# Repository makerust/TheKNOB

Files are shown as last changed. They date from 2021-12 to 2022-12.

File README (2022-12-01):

# TheKNOB

# First Time Setup for development
`git pull --recurse-submodules`
Sketch > Include Library > Add .ZIP Library
Navigate to the ESP library in thirdparty

In:
File > Preference > Additional Boards Manager URLS
Add:
`https://dl.espressif.com/dl/package_esp32_index.json, http://arduino.esp8266.com/stable/package_esp8266com_index.json`
Select:
Tools > Board > Board Manager
Search: ESP32
Install Board Library
Select:
Tools > Board > Board Manager > ESP32 Dev Module

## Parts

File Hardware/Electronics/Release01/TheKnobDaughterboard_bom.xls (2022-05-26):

Comment | Designator | Footprint | JLCPCB Part #
1k | R2 | Resistor_SMD:R_0603_1608Metric | C21190
1.5k | R6 | Resistor_SMD:R_0603_1608Metric | C22843
100k | R17,R19 | Resistor_SMD:R_0603_1608Metric | C25803
100nF | C1 | Capacitor_SMD:C_0603_1608Metric | C14663
10k | R9,R10,R11,R12,R15,R20 | Resistor_SMD:R_0603_1608Metric | C25804
10uF | C4 | Capacitor_SMD:C_0603_1608Metric | C19702
16k | R14 | Resistor_SMD:R_0603_1608Metric | C269411
3.6v | D1,D2 | Diode_SMD:D_SOD-323_HandSoldering | C391443
330R | R5 | Resistor_SMD:R_0603_1608Metric | C23138
33pF | C7,C10,C11 | Capacitor_SMD:C_0603_1608Metric | C1663
47uF | C2,C8,C9 | Capacitor_SMD:C_1206_3216Metric | C68361
3k | R1 | Resistor_SMD:R_0603_1608Metric | C4211
470k | R16,R18 | Resistor_SMD:R_0603_1608Metric | C23178
5.1k | R3,R4 | Resistor_SMD:R_0603_1608Metric | C23186
500mA | F1 | Fuse:Fuse_1206_3216Metric | C70076
6.8uH | L1,L2 | Inductor_SMD:L_1210_3225Metric | C223416
75R | R7,R8 | Resistor_SMD:R_0603_1608Metric | C4275
80k | R13 | Resistor_SMD:R_0603_1608Metric | C23249
AP9101CK | U2 | Package_TO_SOT_SMD:SOT-23-5 | C507889
D_Schottky | D3,D4,D5 | Diode_SMD:D_SOD-123 | C37049
JST PH 2 Pin Surface Mount | J1 | JST_PH_S2B-PH-SM4-TB | C295747
LMR62421XMF/NOPB | U3 | Package_SO:VSSOP-8_3.0x3.0mm_P0.65mm | C206031
MCP73831-5-OT | U1 | Package_TO_SOT_SMD:SOT-23-5 | C424093
Q_NMOS_GSD | Q1,Q2 | Package_TO_SOT_SMD:SOT-23 | C20917
USB_C_Receptacle_USB2.0 | J2 | Connector_USB:USB_C_Receptacle_HRO_TYPE-C-31-M-12 | C165948

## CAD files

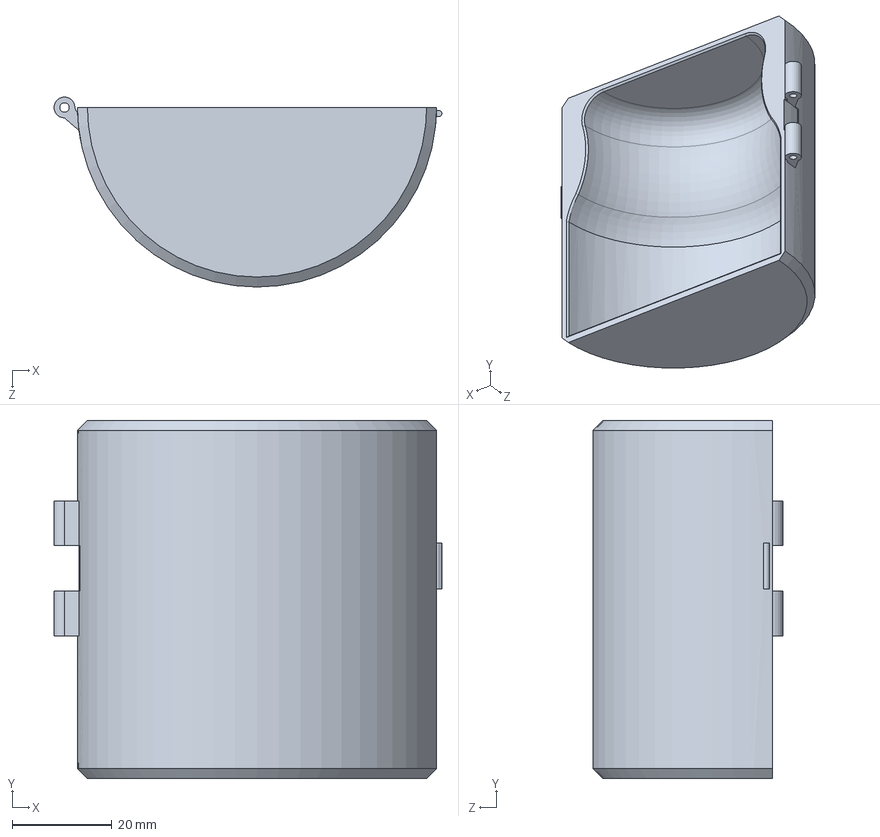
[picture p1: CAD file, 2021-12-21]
Hardware/CaseAndMechanism/SolidworksFiles/Case2_2^KNOBAssembly.SLDPRT
77.7 x 71.7 x 38.1 mm

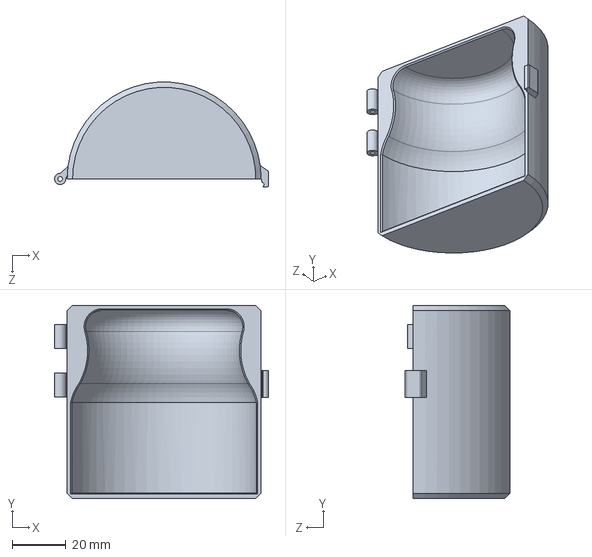
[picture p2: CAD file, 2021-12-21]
Hardware/CaseAndMechanism/SolidworksFiles/Case1^KNOBAssembly.SLDPRT
79.3 x 71.7 x 38.8 mm

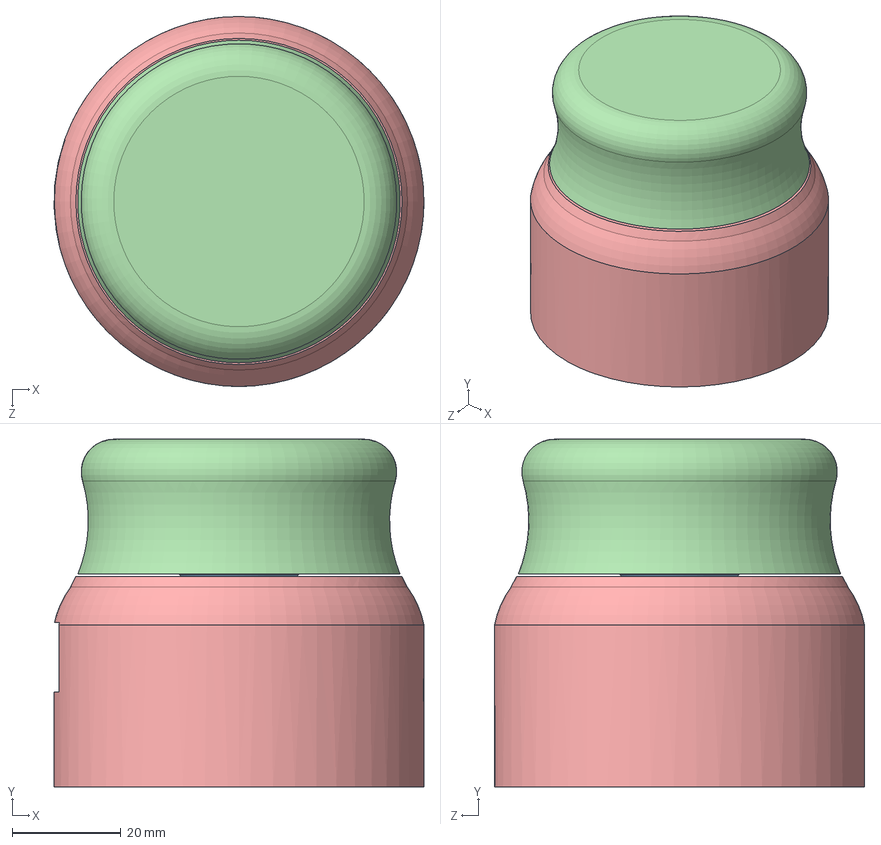
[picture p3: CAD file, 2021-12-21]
Hardware/CaseAndMechanism/SolidworksFiles/KNOBAssembly.SLDASM
68.0 x 63.9 x 68.0 mm
EncoderDevBoard^KNOBAssembly
ESP32DevBoard^KNOBAssembly
5972K91_Ball Bearing
KNOB^KNOBAssembly
KNOBBase^KNOBAssembly
9714K2_Wave Disc Spring
93475A280_18-8 Stainless Steel Washer
LiPoChargeDevBoard
BatteryPrism650mAh
AlpsSKPMAME010 x 2
Bottom_TheKnob
Switch_1587768^KNOBAssembly
NeoPixelPCBA x 3

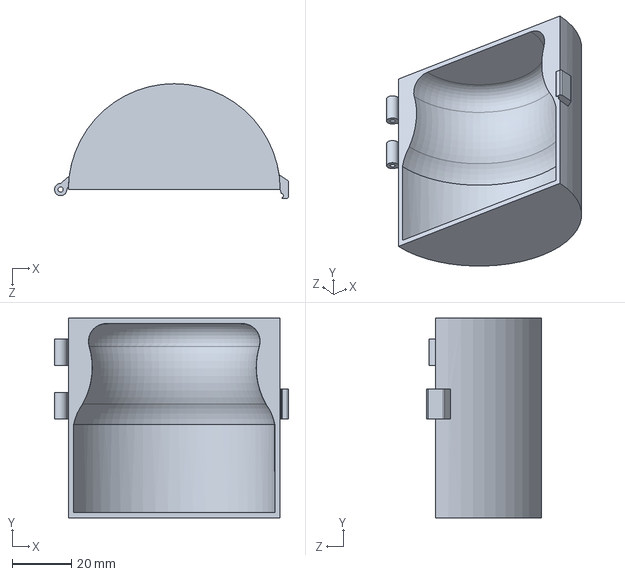
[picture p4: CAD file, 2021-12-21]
Hardware/CaseAndMechanism/SolidworksFiles/Case2^KNOBAssembly.SLDPRT
79.2 x 67.6 x 38.8 mm

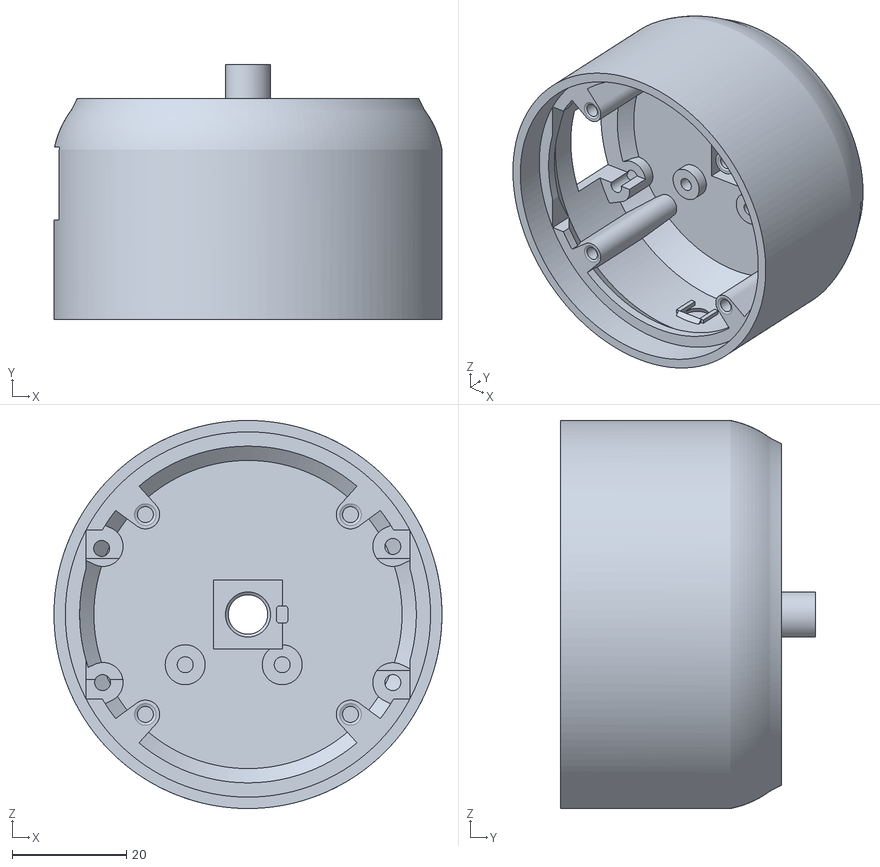
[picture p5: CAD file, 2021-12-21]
Hardware/CaseAndMechanism/STLFiles/Base.STL
68.0 x 44.7 x 68.0

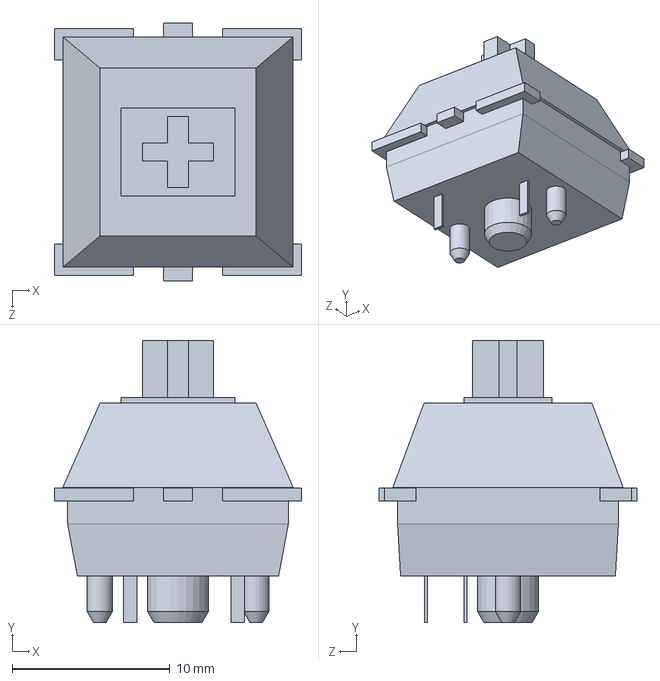
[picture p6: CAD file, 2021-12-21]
Hardware/CaseAndMechanism/SolidworksFiles/cherry mx.SLDPRT
15.6 x 17.9 x 16.3 mm

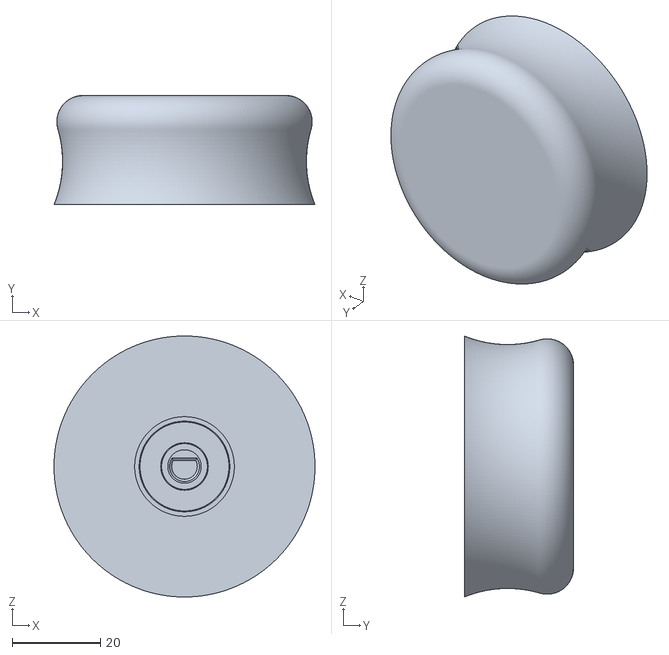
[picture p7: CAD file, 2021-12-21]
Hardware/CaseAndMechanism/STLFiles/Knob.STL
59.3 x 24.8 x 59.3

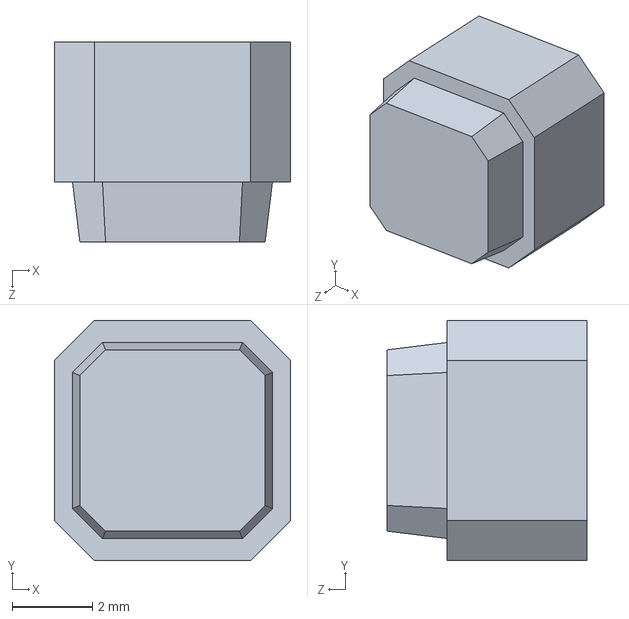
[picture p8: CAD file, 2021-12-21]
Hardware/CaseAndMechanism/SolidworksFiles/AlpsSKPMAME010.SLDPRT
5.90 x 6.00 x 5.00 mm

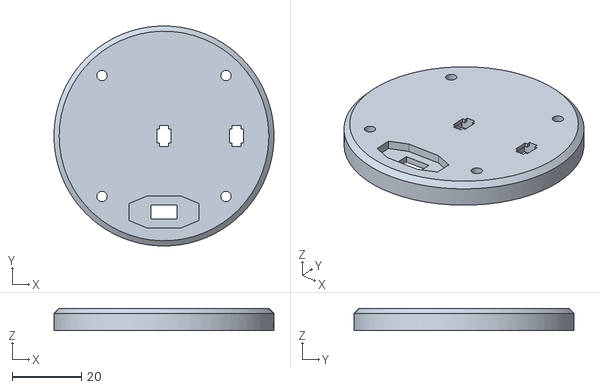
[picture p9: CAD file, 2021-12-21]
Hardware/CaseAndMechanism/STLFiles/Case.STL
63.7 x 63.7 x 6.50

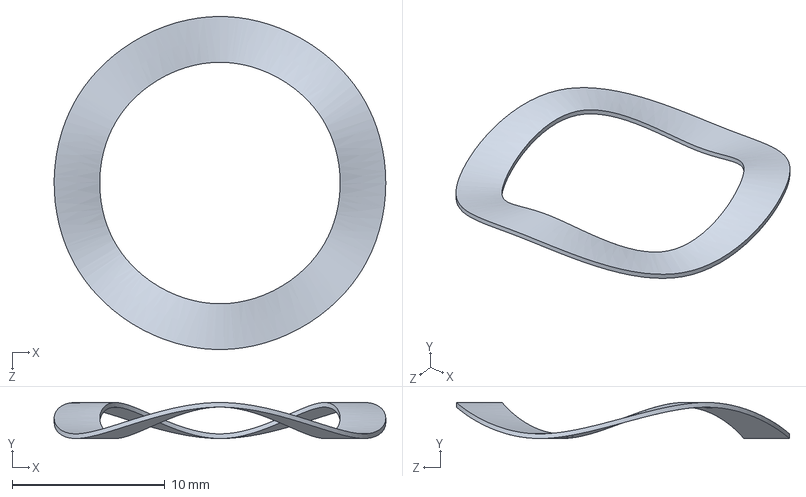
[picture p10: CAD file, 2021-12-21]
Hardware/CaseAndMechanism/SolidworksFiles/9714K2_Wave Disc Spring.SLDPRT
21.7 x 2.36 x 21.8 mm

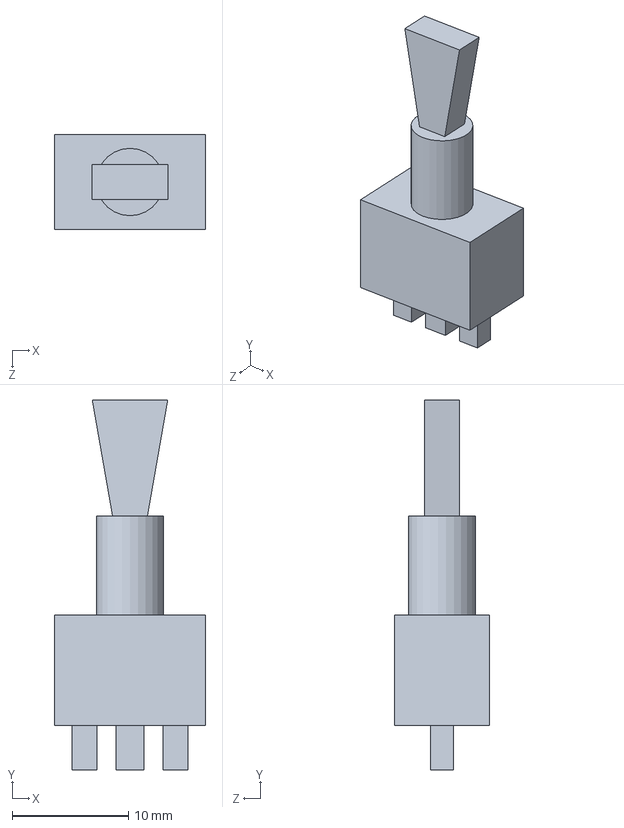
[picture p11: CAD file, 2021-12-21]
Hardware/CaseAndMechanism/SolidworksFiles/ToggleSwitch.SLDPRT
13.0 x 31.9 x 8.15 mm

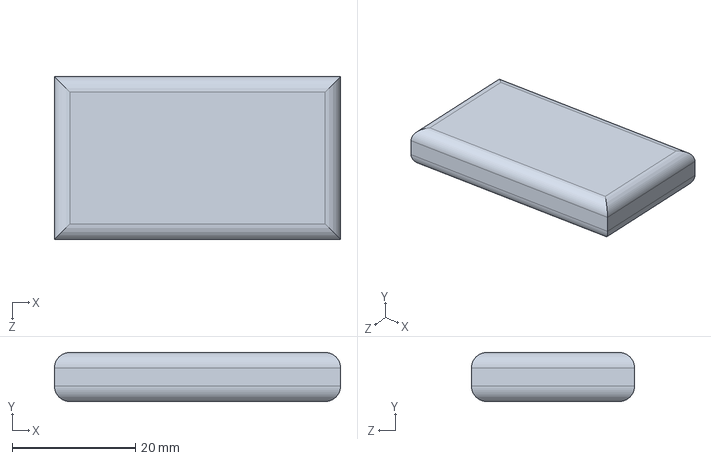
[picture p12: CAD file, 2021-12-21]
Hardware/CaseAndMechanism/SolidworksFiles/BatteryPrism650mAh.SLDPRT
46.5 x 8.00 x 26.5 mm

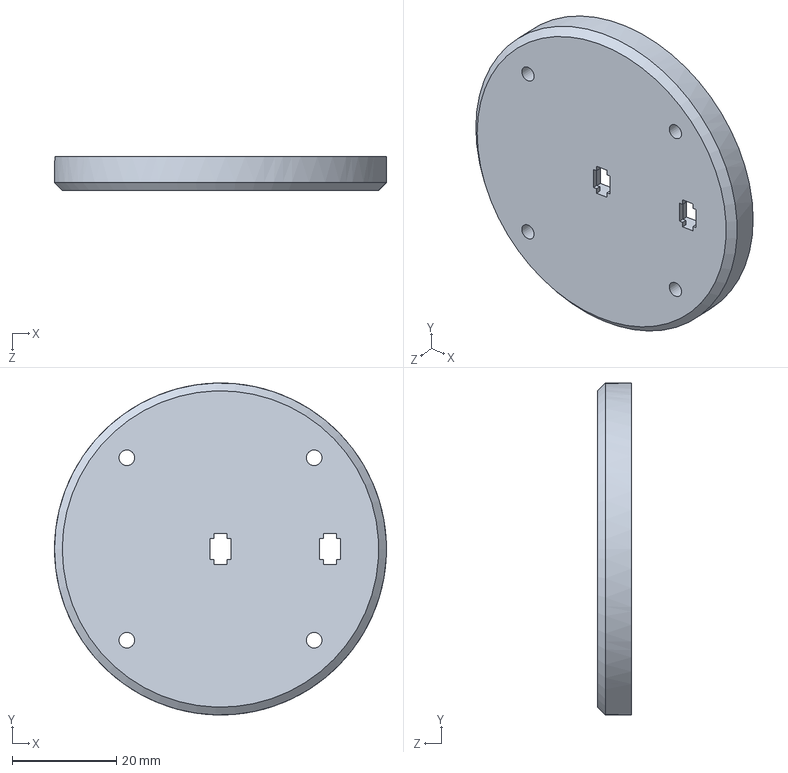
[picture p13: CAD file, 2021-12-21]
Hardware/CaseAndMechanism/SolidworksFiles/BottomButtonTestPrint1.SLDPRT
63.7 x 63.7 x 6.50 mm

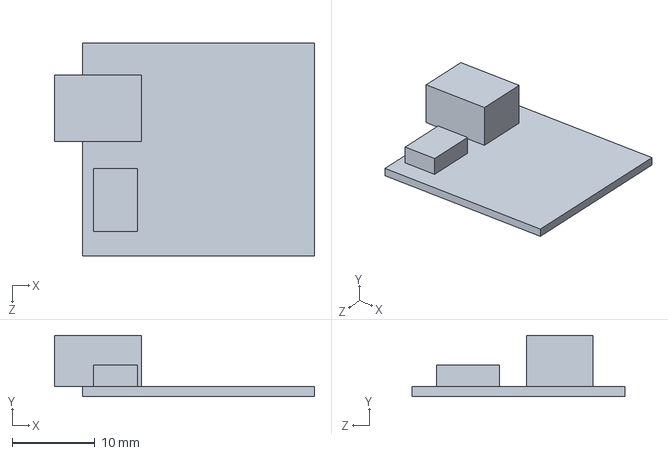
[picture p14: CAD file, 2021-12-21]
Hardware/CaseAndMechanism/SolidworksFiles/LiPoChargeDevBoard.SLDPRT
31.4 x 7.40 x 25.8 mm

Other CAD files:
Hardware/CaseAndMechanism/SolidworksFiles/Bottom_TheKnob.SLDPRT
Hardware/CaseAndMechanism/SolidworksFiles/NeoPixelPCBA.SLDPRT
Hardware/CaseAndMechanism/SolidworksFiles/9714K428_Wave Disc Spring.SLDPRT
Hardware/CaseAndMechanism/SolidworksFiles/98689A118_General Purpose 18-8 Stainless Steel Washer.SLDPRT
Hardware/CaseAndMechanism/SolidworksFiles/5972K91_Ball Bearing.SLDPRT
Hardware/CaseAndMechanism/SolidworksFiles/93475A280_18-8 Stainless Steel Washer.SLDPRT

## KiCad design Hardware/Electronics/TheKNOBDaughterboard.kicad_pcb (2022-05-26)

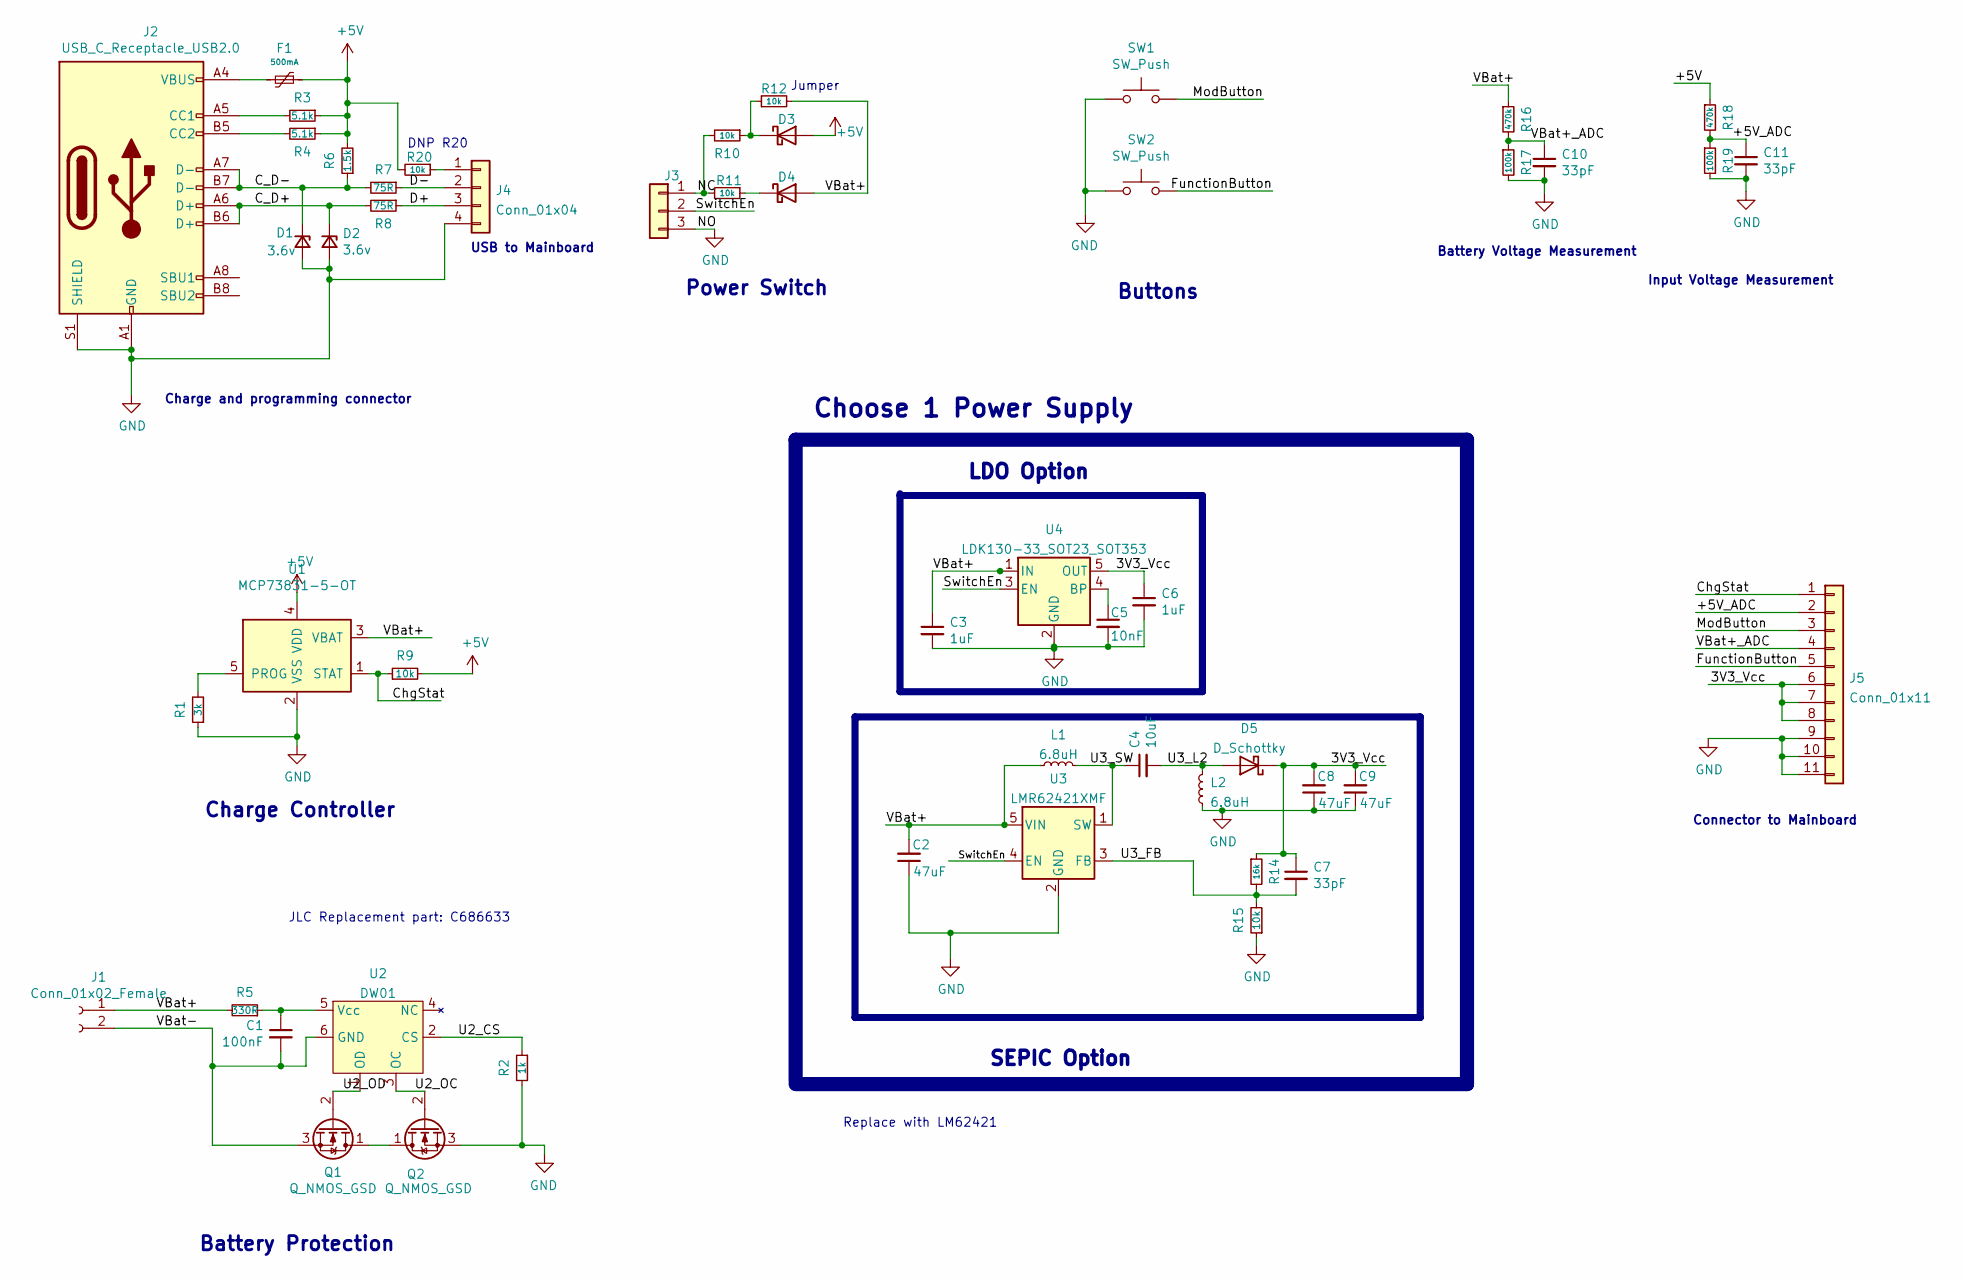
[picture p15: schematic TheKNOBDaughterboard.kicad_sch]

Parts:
C1: 100nF; C_0603_1608Metric
C2, C8, C9: 47uF; C_1206_3216Metric; MFR_PN C3216X5R1A336MTJ00N
C3, C6: 1uF; C_0603_1608Metric
C4: 10uF; C_0603_1608Metric
C5: 10nF; C_0603_1608Metric
C7, C10, C11: 33pF; C_0603_1608Metric
D1, D2: 3.6v; D_SOD-323_HandSoldering; MFR_PN BZT52-B3V6S_R1_00001
D3, D4, D5: D_Schottky; D_SOD-123; MFR_PN 1N5819HW
F1: 500mA; Fuse_1206_3216Metric; MFR_PN nSMD025
J1: Conn_01x02_Female; JST_PH_S2B-PH-SM4-TB_1x02-1MP_P2.00mm_Horizontal
J2: USB_C_Receptacle_USB2.0; USB_C_Receptacle_HRO_TYPE-C-31-M-12; MFR_PN TYPE-C-31-M-12
J3: Conn_01x03; JST_EH_B3B-EH-A_1x03_P2.50mm_Vertical
J4: Conn_01x04; JST_EH_B4B-EH-A_1x04_P2.50mm_Vertical
J5: Conn_01x11; JST_EH_B11B-EH-A_1x11_P2.50mm_Vertical
L1, L2: 6.8uH; L_1210_3225Metric; MFR_PN LBC3225T6R8MR
Q1, Q2: Q_NMOS_GSD; SOT-23; MFR_PN AO3400A
R1: 3k; R_0603_1608Metric
R2: 1k; R_0603_1608Metric
R3, R4: 5.1k; R_0603_1608Metric
R5: 330R; R_0603_1608Metric
R6: 1.5k; R_0603_1608Metric
R7, R8: 75R; R_0603_1608Metric
R9, R10, R11, R12, R15, R20: 10k; R_0603_1608Metric
R14: 16k; R_0603_1608Metric
R16, R18: 470k; R_0603_1608Metric
R17, R19: 100k; R_0603_1608Metric
SW1, SW2: SW_Push; ALPS_SKPM
U1: MCP73831-5-OT; SOT-23-5
U2: DW01; SOT-23-6
U3: LMR62421XMF; SOT-23-5
U4: LDK130-33_SOT23_SOT353; SOT-353_SC-70-5

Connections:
+5V: D3.2 (A), F1.1, R3.1, R4.1, R6.2, R9.2, R18.1, R20.2, U1.4 (VDD)
/3V3_Vcc: C6.1, C7.1, C8.2, C9.2, D5.1 (K), J5.6, J5.7, J5.8, R14.1, U4.5 (OUT)
/+5V_ADC: C11.1, J5.2, R18.2, R19.1
/C_D+: D2.1 (K), J2.A6 (D+), J2.B6 (D+), R8.2
/C_D-: D1.1 (K), J2.A7 (D-), J2.B7 (D-), R6.1, R7.2
/ChgStat: J5.1, R9.1, U1.1 (STAT)
/D+: J4.3, R8.1
/D-: J4.2, R7.1
/FunctionButton: J5.5, SW2.1
/ModButton: J5.3, SW1.1
/NC: J3.1, R10.2, R11.2
/SwitchEn: J3.2, U3.4 (EN), U4.3 (EN)
/U2_CS: R2.1, U2.2 (CS)
/U2_OC: Q2.2 (G), U2.3 (OC)
/U2_OD: Q1.2 (G), U2.1 (OD)
/U3_FB: C7.2, R14.2, R15.2, U3.3 (FB)
/U3_L2: C4.2, D5.2 (A), L2.2
/U3_SW: C4.1, L1.2, U3.1 (SW)
/VBat+: C2.2, C3.1, D4.2 (A), J1.1, J1.MP, L1.1, R5.2, R12.2, R16.1, U1.3 (VBAT), U3.5 (VIN), U4.1 (IN)
/VBat+_ADC: C10.1, J5.4, R16.2, R17.1
/VBat-: C1.2, J1.2, Q1.3 (S), U2.6 (GND)
GND: C2.1, C3.2, C5.2, C6.2, C8.1, C9.1, C10.2, C11.2, D1.2 (A), D2.2 (A), J2.A1 (GND), J2.A12 (GND), J2.B1 (GND), J2.B12 (GND), J2.S1 (SHIELD), J3.3, J4.4, J5.9, J5.10, J5.11, L2.1, Q2.3 (S), R1.1, R2.2, R15.1, R17.2, R19.2, SW1.2, SW2.2, U1.2 (VSS), U3.2 (GND), U4.2 (GND)
unnamed: C1.1, R5.1, U2.5 (Vcc)
unnamed: C5.1, U4.4 (BP)
unnamed: D3.1 (K), R10.1, R12.1
unnamed: D4.1 (K), R11.1
unnamed: F1.2, J2.A4 (VBUS), J2.A9 (VBUS), J2.B4 (VBUS), J2.B9 (VBUS)
unnamed: J2.A5 (CC1), R3.2
unnamed: J2.B5 (CC2), R4.2
unnamed: J4.1, R20.1
unnamed: Q1.1 (D), Q2.1 (D)
unnamed: R1.2, U1.5 (PROG)

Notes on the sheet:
USB to Mainboard
LDO Option
Connector to Mainboard
Charge and programming connector
Power Switch
Input Voltage Measurement
Replace with LM62421
Charge Controller
Battery Protection
DNP R20
Jumper
Choose 1 Power Supply
SEPIC Option
JLC Replacement part: C686633
Buttons
Battery Voltage Measurement

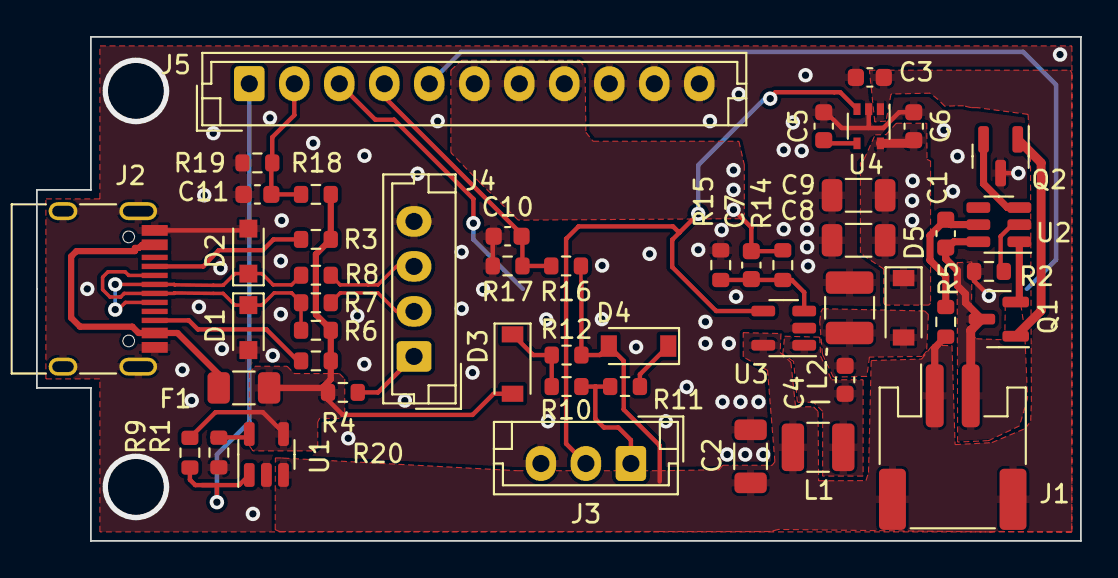
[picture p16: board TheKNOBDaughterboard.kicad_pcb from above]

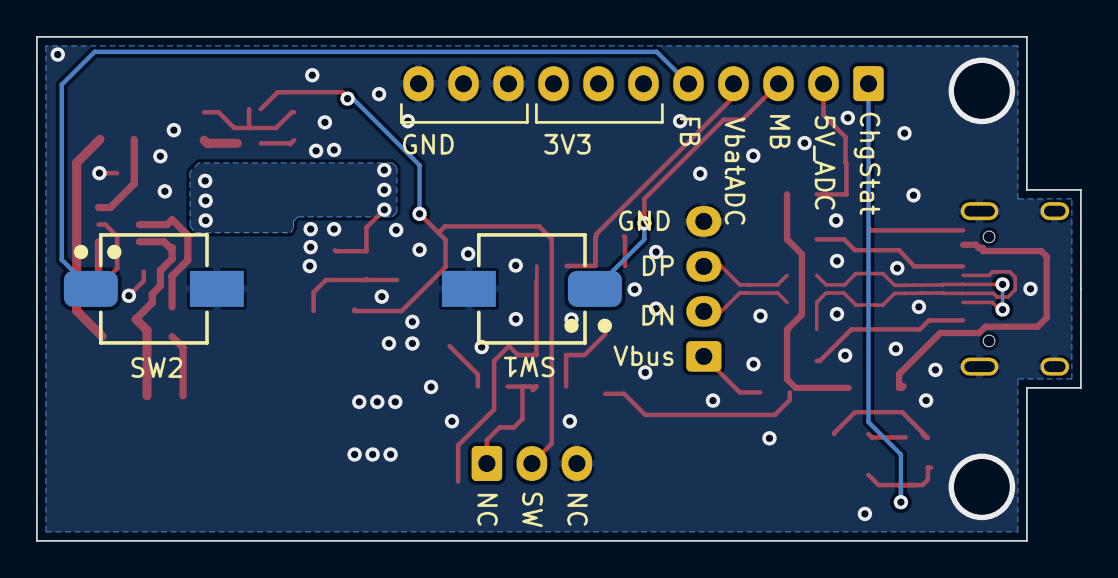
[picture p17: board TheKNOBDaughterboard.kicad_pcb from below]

Board: 2 copper layers, 58.0 x 28.0 mm, 51 parts (2 on the bottom side), 32 nets.

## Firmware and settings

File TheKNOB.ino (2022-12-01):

/* -- The Kinesthetic Novelty Oblate Button --
*/

#include <driver/dac.h>
#include <BleKeyboard.h>//works with version 0.2.3 of the library
//https://github.com/T-vK/ESP32-BLE-Keyboard/tree/0.2.3
BleKeyboard bleKeyboard("The KNOB", "Pangolin Design Team", 69);
#include <Adafruit_NeoPixel.h>
#include "mailbox.hpp"


#define DEBUG

#ifdef DEBUG
#define DEBUG_PRINT(x) Serial.print(x)
#define DEBUG_PRINTLN(x) Serial.println(x)
#else
#define DEBUG_PRINT(x)
#define DEBUG_PRINTLN(x)
#endif


//Pin defines
constexpr auto BATT_VOLT_PIN = 34;
constexpr auto CHG_STAT = 35;
constexpr auto USB_VOLT_PIN = 32;
constexpr auto BUTTON_1 = 33;
constexpr auto BUTTON_2 = 26;
constexpr auto ENCODER_BUTTON = 27;
constexpr auto ENCODER_B = 14;
constexpr auto ENCODER_A = 13;
constexpr auto LED_PIN = 4;


#define LED_COUNT 3


enum class Action : uint8_t{
  no_action = 0,
  fast_forward = 2,
  reverse = 3,
  volume_up = 5,
  volume_down = 6,
  function_press = 1,
  encoder_press = 4
};

Adafruit_NeoPixel strip(LED_COUNT, LED_PIN, NEO_GRB + NEO_KHZ800);


RTC_DATA_ATTR int bootCount = 0;
RTC_DATA_ATTR int wakeDelayB = 0;

/*
  ESP32 ADC Data:
  uses a 47k, 10k res div on bat voltage pin to scale 4.7v to 0.75v
  0-4095 bit depth
  ref 1085mV
  vi = (vo * (Rb + Rt))/ Rb
  scaling ratio = 5.7
  batt volt: 3.80v res div 640mV
  ADC 4095
*/

constexpr float adc_volt_div_correction = 5.7;
constexpr float refV = 1.085;
constexpr float precB = 4095;
constexpr float usbVoltThresh = 0.6;


float volt_read(uint8_t pin, float refV, float precB) {
  float batt_bits = analogRead(pin);
  float voltage = (batt_bits * refV) / precB;
  return voltage;
}

int batt_chg_percent(uint8_t pin, float refV, float precB, float resDivRatio) {
  //This method will be super flawed for a Li battery
  float batt_volt_roll = 0;
  int batt_buff_size = 30;
  for(int i =0; i <= (batt_buff_size-1); i++){
    batt_volt_roll += (resDivRatio * volt_read(pin, refV, precB));
    //delay(3);
  }

  float batt_volt_now = batt_volt_roll/batt_buff_size;
  //float batt_volt_now = resDivRatio * volt_read(pin, refV, precB);

  if (batt_volt_now >= 4.1 )
    return 100;
  else if (batt_volt_now >= 3.9)
    return 80;
  else if (batt_volt_now >= 3.8)
    return 60;
  else if (batt_volt_now >= 3.7)
    return 40;
  else
    return 20;
}

//Global mailbox array
mailbox<Action, 40> key_mailbox;

//This is used as a mutex in ESP code to handle interrupts
struct critical_section{
  static portMUX_TYPE mux;
  critical_section(){
    portENTER_CRITICAL(&mux);//disable interrupts
  }
  ~critical_section(){
    portEXIT_CRITICAL(&mux);//enable interrupts
  }
};
portMUX_TYPE critical_section::mux = portMUX_INITIALIZER_UNLOCKED;

void IRAM_ATTR enc_ISR() {
  auto c = critical_section{};

  //-- encoder states are read first since they are fast
  // other button state read after debounce
  int enc_clk_now = digitalRead(ENCODER_A);
  int enc_dt_now = digitalRead(ENCODER_B);

  static int enc_composit ;//byte pack of pinstates

  //-- variables for Debouncing signals
  static unsigned long last_interrupt_time = 0;
  unsigned long interrupt_time = millis();

  if (interrupt_time - last_interrupt_time > 0) { //debounces interrupts| 0 WORKED VERY WELL
    last_interrupt_time = interrupt_time;

    //Build a byte of encoder states
    int button_state_now = (!digitalRead(BUTTON_1));

    enc_composit |= (enc_dt_now << 3);
    enc_composit |= (enc_clk_now << 2);

    //Position stored here. 0: no change, 1: CW, -1: CCW
    int enc_position = 0;

    switch (enc_composit) {
      case 2:
        enc_position = 1;
        break;
      case 1:
        enc_position = -1;
        break;
      default:
        break;
    }
    
    enc_composit = enc_composit >> 2;

    /* -- Regarding the cases

        0 0 0 0 | 0 | X
        0 0 0 1 | 1 | CCW
        0 0 1 0 | 2 | CW
        0 0 1 1 | 3 | X
        0 1 0 0 | 4 | CW
        0 1 0 1 | 5 | X
        0 1 1 0 | 6 | X
        0 1 1 1 | 7 | CCW
        1 0 0 0 | 8 | CCW
        1 0 0 1 | 9 | X
        1 0 1 0 | 10| X
        1 0 1 1 | 11| CW
        1 1 0 0 | 12| X
        1 1 0 1 | 13| CW
        1 1 1 0 | 14| CCW
        1 1 1 1 | 15| X

    */

    //in practice, the mailbox is largely unnecessary as it never gets filled
    //past the first position
    if (!key_mailbox.is_full()) { //Check to not overflow the mailbox array.
      // If service cannot empty in time, itmes are not added to mailbox

      if (button_state_now == 1) { //if FFRW key pressed, encoder encodes for FFRW
        if (enc_position > 0) {
          key_mailbox.push_back(Action::fast_forward);
        }
        if (enc_position < 0) {
          key_mailbox.push_back(Action::reverse);
        }
      }
      else {
        if (enc_position > 0) { //if not pressed, encode volume
          key_mailbox.push_back(Action::volume_up);
        }
        else if (enc_position < 0) {
          key_mailbox.push_back(Action::volume_down);
        }
      }
    }
  }
  return;
}

void IRAM_ATTR key_detect() {
  auto c = critical_section{};
  static unsigned long last_interrupt_time2 = 0;
  unsigned long interrupt_time2 = millis();

  if (interrupt_time2 - last_interrupt_time2 > 300) { //debounces interrupts
    last_interrupt_time2 = interrupt_time2;
    int encoder_button_state = digitalRead(ENCODER_BUTTON);
    int function_button_state = digitalRead(BUTTON_2);

    if (!key_mailbox.is_full()) {
      if (function_button_state == 0) { //function key press.
        key_mailbox.push_back(Action::function_press);
      }
      if (encoder_button_state == 0) { //encoder key press.
        key_mailbox.push_back(Action::encoder_press);
      }
    }
  }
}


#define LED_BRIGHTNESS   5
uint32_t red = strip.ColorHSV(0, 255, LED_BRIGHTNESS);
uint32_t green = strip.ColorHSV(21845, 255, LED_BRIGHTNESS);
uint32_t blue = strip.ColorHSV(43690, 255, LED_BRIGHTNESS);
uint32_t white = strip.ColorHSV(0, 0, LED_BRIGHTNESS);
uint32_t orange = strip.ColorHSV(5461, 255, LED_BRIGHTNESS);


bool blink(bool led_stat, uint32_t color, uint32_t bkgd = 0) {
  unsigned long time_millis = millis();
  static unsigned long set_time_millis;
  if (led_stat == 0 && time_millis % 2750 == 1) {
    for (int i = 0;  i < (LED_COUNT); i++)
    {
      strip.setPixelColor(i, color);
    }
    strip.show();
    set_time_millis = time_millis;
    led_stat = 1;
  }
  if (led_stat == 1 && ((time_millis - set_time_millis) > 250)) {
    for (int j = 0; j < (LED_COUNT); j++)
    {
      strip.setPixelColor(j, bkgd);
    }
    strip.show();
    led_stat = 0;
  }
  return led_stat;
}

bool light(bool led_stat, uint32_t color) {
  for (int i = 0;  i < (LED_COUNT); i++)
  {
    strip.setPixelColor(i, color);
  }
  strip.show();
  led_stat = 1;

  return led_stat;
}

void setup() {
  pinMode(LED_PIN, OUTPUT);
  strip.begin();
  strip.show(); // Initialize all pixels to 'off'
  for (int i = 0; i < LED_COUNT; i++)
  {
    strip.setPixelColor(i, white);
  }
  strip.show();

  key_mailbox.fill(Action::no_action);


  dac_output_disable(DAC_CHANNEL_1);
  dac_output_disable(DAC_CHANNEL_2);
  // Disable DAC1
  REG_CLR_BIT(RTC_IO_PAD_DAC1_REG, RTC_IO_PDAC1_XPD_DAC);
  REG_SET_BIT(RTC_IO_PAD_DAC1_REG, RTC_IO_PDAC1_DAC_XPD_FORCE);
  // Disable DAC2
  REG_CLR_BIT(RTC_IO_PAD_DAC2_REG, RTC_IO_PDAC2_XPD_DAC);
  REG_SET_BIT(RTC_IO_PAD_DAC2_REG, RTC_IO_PDAC2_DAC_XPD_FORCE);
  // make the pushButton pin an input:
  pinMode(BUTTON_2, INPUT_PULLUP);
  attachInterrupt(digitalPinToInterrupt(BUTTON_2), key_detect, FALLING);
  pinMode(BUTTON_1, INPUT_PULLUP);
  //attachInterrupt(digitalPinToInterrupt(BUTTON_1), key_detect, FALLING);
  pinMode(ENCODER_BUTTON, INPUT);
  attachInterrupt(digitalPinToInterrupt(ENCODER_BUTTON), key_detect, FALLING);
  pinMode(ENCODER_A, INPUT);
  attachInterrupt(digitalPinToInterrupt(ENCODER_A), enc_ISR, CHANGE);
  pinMode(ENCODER_B, INPUT);
  attachInterrupt(digitalPinToInterrupt(ENCODER_B), enc_ISR, CHANGE);
  pinMode(BATT_VOLT_PIN, INPUT);


  // initialize control over the keyboard:
#ifdef DEBUG
  Serial.begin(115200);
  Serial.println("Starting BLE work!");
#endif

  bleKeyboard.begin();
  //strip.show();
  delay(200);

  analogSetAttenuation(ADC_0db);
  analogSetWidth(12);

  bleKeyboard.setBatteryLevel(batt_chg_percent(BATT_VOLT_PIN, refV, precB, 5.7));

}



void loop() {

  static uint32_t led_bkgd = 0;
  //timing variables for power saving
  static unsigned long last_send_time = 0;
#ifdef DEBUG
  unsigned long power_timeout_debug = 3000000;
#else
  unsigned long power_timeout_debug = 300000; //Five minutes in ms
#endif
  static bool led_on = 0;
  static bool usbPower = 0;

  if (wakeDelayB == 1) { //A few things to try to have a more seamless wake

    strip.setPixelColor(0, 0, 0, 12);
    strip.show();
    bleKeyboard.setBatteryLevel(batt_chg_percent(1, 1.2, 4096, 5.7));//mostly works
    DEBUG_PRINT("Battery level ");
    DEBUG_PRINT(batt_chg_percent(BATT_VOLT_PIN, 1.1, 4095, 5.7));
    DEBUG_PRINTLN("%");
    DEBUG_PRINTLN("Waking up");
    delay(1000);
    wakeDelayB = 0;
    usbPower = 0;

  }

  usbPower = (volt_read(USB_VOLT_PIN, refV, precB) > usbVoltThresh);

  if (bleKeyboard.isConnected() && wakeDelayB == 0) {

    if (usbPower) {
      led_on = light(led_on, green);
    }
    else {
      led_on = blink(led_on, green, led_bkgd);
    }

    auto count = key_mailbox.count();
    if (count != 0) {
      DEBUG_PRINT("Send Mailbox size: ");
      DEBUG_PRINTLN(count);

      for (auto i = count; i > 0; i--) {
        switch (key_mailbox.pop_front()) {
          case Action::function_press:
            bleKeyboard.write(KEY_F8);
            DEBUG_PRINTLN("Send Function Key");
            break;
          case Action::fast_forward:
            bleKeyboard.write(KEY_MEDIA_NEXT_TRACK);
            DEBUG_PRINTLN("Send FF Key");
            break;
          case Action::reverse:
            bleKeyboard.write(KEY_MEDIA_PREVIOUS_TRACK);
            DEBUG_PRINTLN("Send RW Key");
            break;
          case Action::encoder_press:
            bleKeyboard.write(KEY_MEDIA_PLAY_PAUSE);
            DEBUG_PRINTLN("Send Play Pause Key");
            break;
          case Action::volume_up:
            bleKeyboard.write(KEY_MEDIA_VOLUME_UP);
            DEBUG_PRINTLN("Send UP Key");
            break;
          case Action::volume_down:
            bleKeyboard.write(KEY_MEDIA_VOLUME_DOWN);
            DEBUG_PRINTLN("Send DOWN Key");
            break;
          default:
            break;
        }
        last_send_time = millis();
      }
    }
  }

  else {
    if (usbPower) {
      led_on = light(led_on, red);
    }
    else {
      led_on = blink(led_on, red, led_bkgd);
    }
    if (millis() % 1000 == 1) {
      DEBUG_PRINTLN("Disconnected");
      DEBUG_PRINT("Battery voltage :");
      DEBUG_PRINTLN(5.7 * volt_read(BATT_VOLT_PIN, refV, precB));
      DEBUG_PRINT("ADC raw read :");
      DEBUG_PRINTLN(analogRead(BATT_VOLT_PIN));
      DEBUG_PRINT("USB Power? ");
      DEBUG_PRINTLN(usbPower);
      DEBUG_PRINT("USB voltage: ");
      DEBUG_PRINTLN(5.7 * volt_read(USB_VOLT_PIN, refV, precB));
    }
  }

  //--sleep loop
  if ( (millis()) - last_send_time > power_timeout_debug) {
    strip.setPixelColor(0, blue);
    strip.show();
    DEBUG_PRINTLN("Enter sleep mode");
    wakeDelayB = 1;
    delay(200);
    strip.setPixelColor(0, 0, 0, 0);
    strip.show();
    usbPower = 0;
    esp_sleep_enable_ext0_wakeup(GPIO_NUM_27, 0);//Needs to be the same number as ENCODER_BUTTON
    esp_deep_sleep_start();
  }

  //-- battery charge update
  if (millis() % 600 == 1) {//60000
    static int batt_chg = 69;
    int batt_chg_now =  batt_chg_percent(BATT_VOLT_PIN, refV, precB, 5.7);
    if (batt_chg_now != batt_chg or batt_chg == 69) {
      batt_chg = batt_chg_now;
      bleKeyboard.setBatteryLevel(batt_chg);
      DEBUG_PRINT("Battery Level set to ");
      DEBUG_PRINTLN(batt_chg);
      if (batt_chg <= 20){
        led_bkgd = orange;
        DEBUG_PRINTLN("Bkgd color changed to orange.");
      }
      else{
        led_bkgd = 0;
      }
    }
  }
}

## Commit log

2021-09-30 Simplified encoder code, split button ISR to own function
2021-09-30 new encoder code. doesn't work
    [TheKNOB.ino]
2021-10-04 replaced noInterrupt() function with mutex and critical section
    [TheKNOB.ino]
2021-10-15 fixes issue 1 with debug macro. Adds battery level set. Adds better wakeup handler.
    [TheKNOB.ino]
2021-12-21 added hardware folder containing electronics hardware design files, hardware stl files and hardware design files
    [5972K91_Ball Bearing.SLDPRT, 93475A280_18-8 Stainless Steel Washer.SLDPRT, 9714K2_Wave Disc Spring.SLDPRT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]
2021-12-23 added Gerbers, Bom and Pick and place files.
    [TheKNOBDaughterboard-B_Cu.gbr, TheKNOBDaughterboard-B_Mask.gbr, TheKNOBDaughterboard-B_Paste.gbr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]
2021-12-23 add 3d files, changes to sch and pcb
    [TheKNOBDaughterboard.kicad_pcb, TheKNOBDaughterboard.kicad_sch]
2021-12-26 Batt Protection and SMPS chip changed due to chip shortage
    [TheKNOBDaughterboard-B_Cu.gbr, TheKNOBDaughterboard-B_Mask.gbr, TheKNOBDaughterboard-B_Paste.gbr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]
2022-05-26 Changed LED colorspace to HSV so that brightness can be easily changed per housing material, added battery read buffer/average, added background color to flash and fuction to have orange background w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
2022-11-26 Add ESP32-BLE as submodule
2022-11-28 Replaces manual critical section cleanup with RAII magic
    [TheKNOB.ino]
2022-11-28 simplify charge lookup
2022-11-29 Replace mailbox with c++ Adds mailbox.hpp, removes definitions
    [TheKNOB.ino]
